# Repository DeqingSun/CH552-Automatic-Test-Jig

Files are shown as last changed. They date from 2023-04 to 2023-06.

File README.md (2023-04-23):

# CH552-Automatic-Test-Jig
This is a test jig that do automatic hardware test for CH55xduino

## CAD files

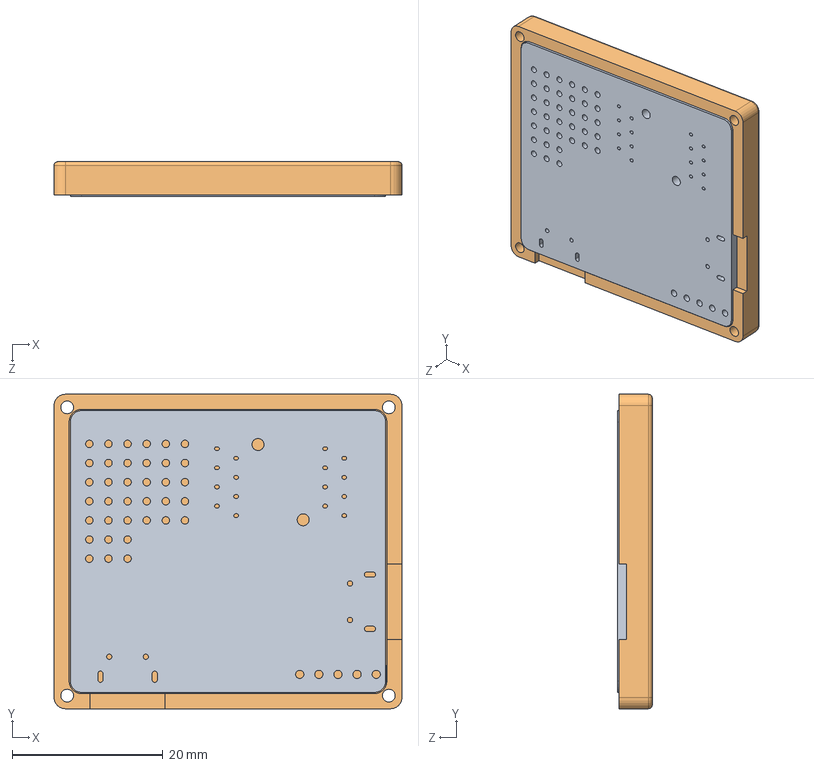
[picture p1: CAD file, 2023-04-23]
PCB/ch552_test_pcb_assembly.SLDASM
46.2 x 41.8 x 4.60 mm
ch552_test_pcb
ch552_test_pcb_case

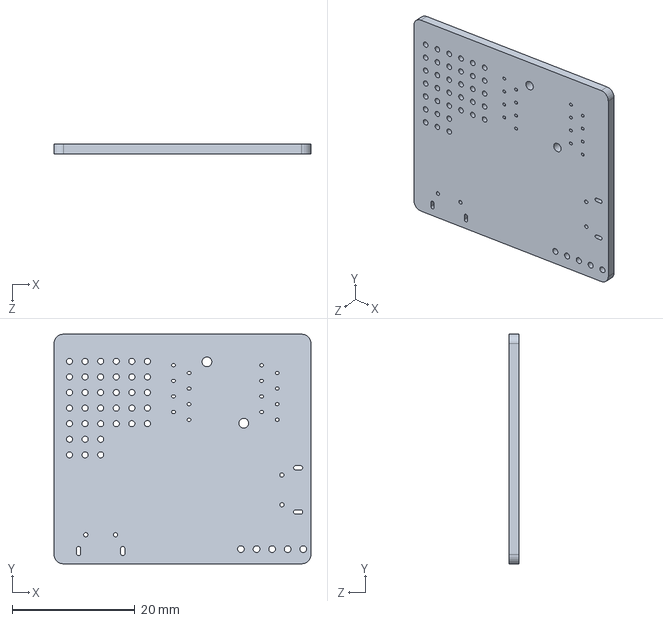
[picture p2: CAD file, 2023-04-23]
PCB/ch552_test_pcb.SLDPRT
41.9 x 37.4 x 1.60 mm

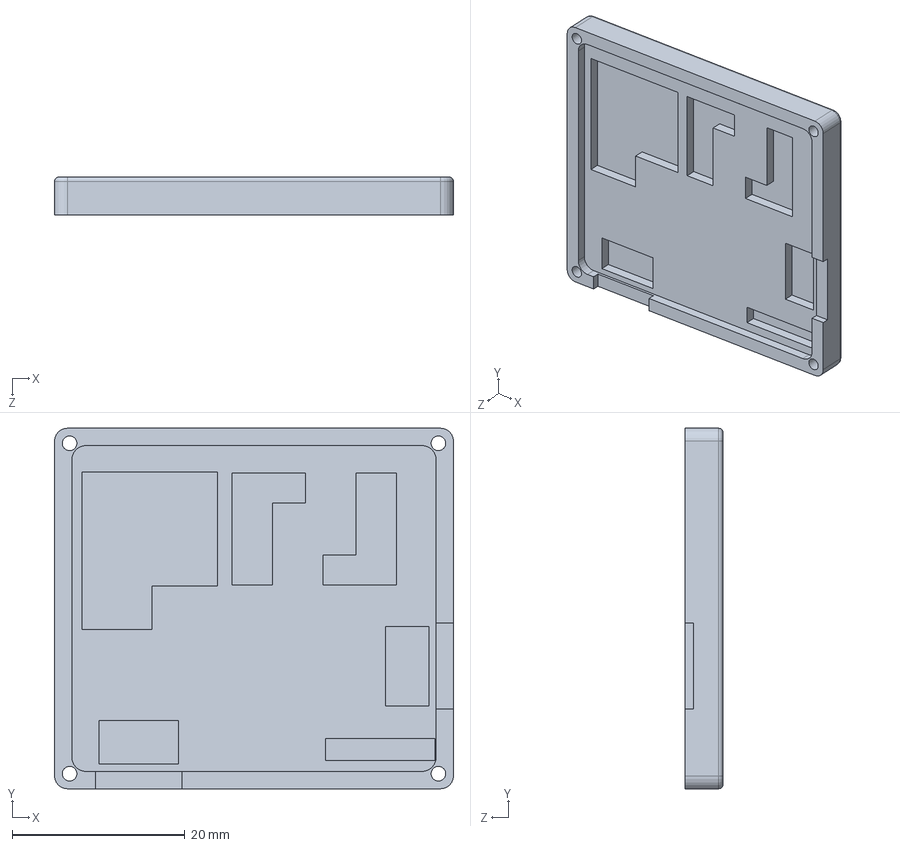
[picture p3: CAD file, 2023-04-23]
PCB/ch552_test_pcb_case.SLDPRT
46.2 x 41.8 x 4.40 mm

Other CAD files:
PCB/ch552_test_pcb_case.STL

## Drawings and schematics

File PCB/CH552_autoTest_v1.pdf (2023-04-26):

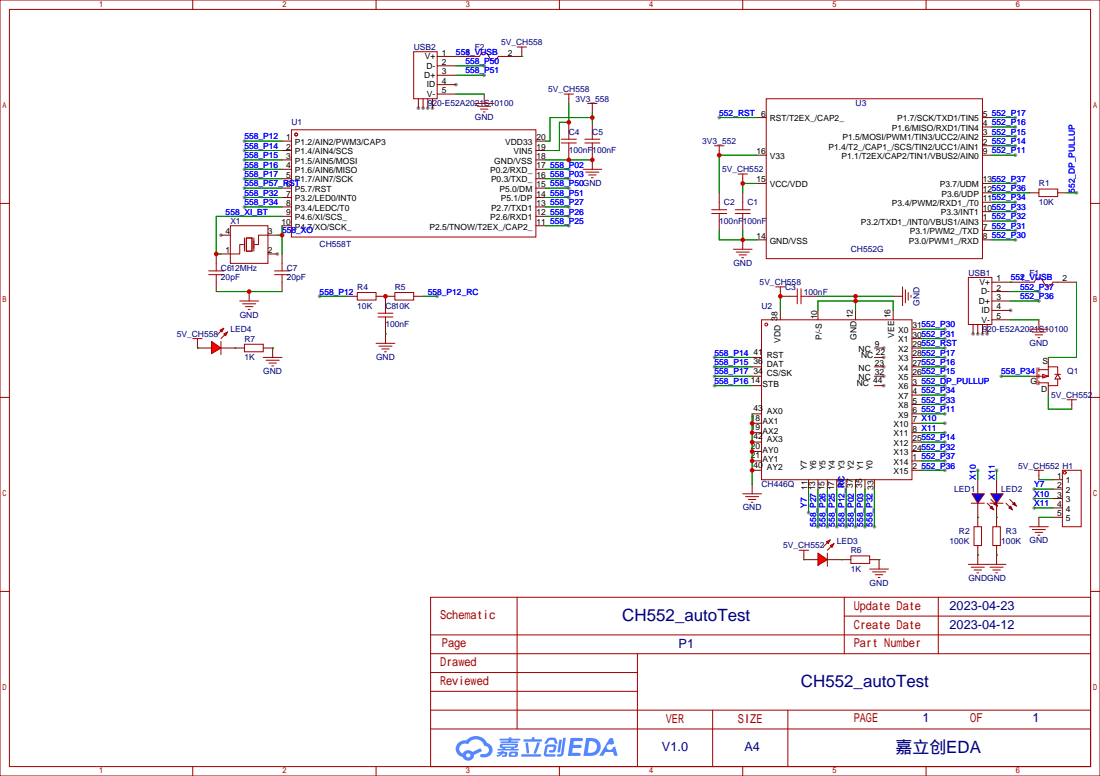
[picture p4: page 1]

1

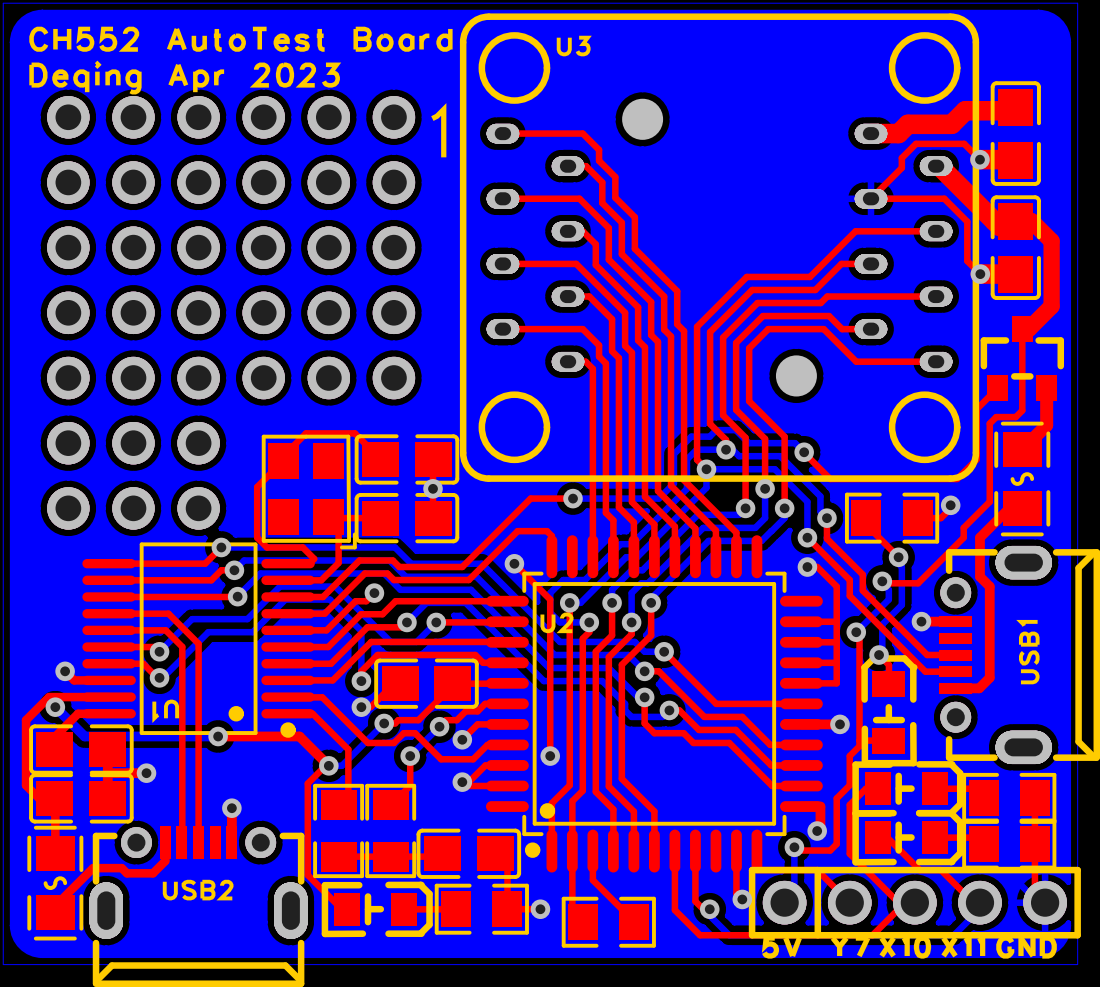
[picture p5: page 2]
5VY7X10X11GND; USB1; USB2

CH552 AutoTest Board Deqing Apr 2023

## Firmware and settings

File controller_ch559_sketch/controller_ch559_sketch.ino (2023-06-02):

//compiled with CH559, CH55xduino 0.0.17
//userUsbCdc used for customized description

#ifndef USER_USB_RAM
#error "This example needs to be compiled with a USER USB setting"
#endif

#include "src/userUsbCdc/USBCDC.h"
#include "ch446q_driver.h"
#include "pinUtil.h"
#include "util.h"

char rxSerialBuffer[16];
uint8_t rxSerialBufferPtr = 0;
uint8_t digitalPinSubscribed = 255;
uint8_t analogPinSubscribed = 255;
uint32_t digitalPinSubscribedLastPrintTime = 0;
uint32_t analogPinSubscribedLastPrintTime = 0;

char uart0RxBuffer[64];
uint8_t uart0RxBufferPtr = 0;
uint32_t uart0RxLastReceiveTime = 0;
char uart1RxBuffer[64];
uint8_t uart1RxBufferPtr = 0;
uint32_t uart1RxLastReceiveTime = 0;
volatile __bit rebootTargetInsteadOfSelfOn1200 = false;
volatile __bit needRebootTargetFlag = false;

void setup() {
  CH552_power(true);

  USBInit();
  CH446Q_init();
  CH446Q_reset();

}

void loop() {

  while (USBSerial_available()) {
    char serialChar = USBSerial_read();
    if ((serialChar == '\n') || (serialChar == '\r') ) {
      rxSerialBuffer[rxSerialBufferPtr] = '\0';
      if (rxSerialBufferPtr > 0) {
        //USBSerial_println(rxSerialBuffer);
        switch (rxSerialBuffer[0])
        {
          case 'I':
            if (rxSerialBufferPtr == 1) {
              CH446Q_reset();
              restoreAllPins();
              digitalPinSubscribed = 255;
              analogPinSubscribed = 255;
              USBSerial_println("I:Init System");
            }
            break;
          case 'C':
          case 'c':
            //connect channels on CH446Q
            if (rxSerialBufferPtr == 3) {
              uint8_t xChannel = hexToUchar(rxSerialBuffer[1]);
              uint8_t yChannel = hexToUchar(rxSerialBuffer[2]);
              uint8_t onOFF = (rxSerialBuffer[0] == 'C') ? 1 : 0;

              if ( (xChannel < 16) && (yChannel < 8)) {
                CH446Q_switch_channel(xChannel, yChannel, onOFF);
                USBSerial_print(rxSerialBuffer[0]);
                USBSerial_print(":Turn ");
                if (onOFF == 1) {
                  USBSerial_print("ON");
                } else {
                  USBSerial_print("OFF");
                }
                USBSerial_print(" X:");
                USBSerial_print(xChannel);
                USBSerial_print(", Y:");
                USBSerial_println(yChannel);
              }
            }
            break;
          case 'B':
            if (rxSerialBufferPtr == 1) {
              CH552_enter_bootloader();
              USBSerial_println("B: CH552 boot mode");
            }else if (rxSerialBufferPtr == 2) {
              if (rxSerialBuffer[1] == 'E'){
                rebootTargetInsteadOfSelfOn1200 = true;
                USBSerial_println("BE: CH552 reboot target on 1200");
              }else if (rxSerialBuffer[1] == 'e'){
                rebootTargetInsteadOfSelfOn1200 = false;
                USBSerial_println("Be: CH552 reboot self on 1200");
              }
            }
            break;
          case 'b':
            if (rxSerialBufferPtr == 1) {
              CH552_reboot_usercode();
              USBSerial_println("b: CH552 reboot usercode");
            }
            break;
          case 'R':
          case 'r':
            if (rxSerialBufferPtr == 3) {
              uint8_t pin = hexToUchar(rxSerialBuffer[1]) * 10 + hexToUchar(rxSerialBuffer[2]);
              uint8_t pinStatus = readPin(pin);
              USBSerial_print(rxSerialBuffer[0]);
              USBSerial_print(rxSerialBuffer[1]);
              USBSerial_print(rxSerialBuffer[2]);
              USBSerial_print((char)':');
              if (pinStatus == PIN_ERROR) {
                USBSerial_println("not valid");
              } else {
                USBSerial_println((char)('0' + pinStatus));
                if (rxSerialBuffer[0] == 'R') {
                  digitalPinSubscribed = 255;
                } else {
                  digitalPinSubscribed = pin;
                  digitalPinSubscribedLastPrintTime = millis();
                }
              }
            }
            break;
          case 'A':
          case 'a':
            if (rxSerialBufferPtr == 3) {
              uint8_t pin = hexToUchar(rxSerialBuffer[1]) * 10 + hexToUchar(rxSerialBuffer[2]);
              USBSerial_print(rxSerialBuffer[0]);
              USBSerial_print(rxSerialBuffer[1]);
              USBSerial_print(rxSerialBuffer[2]);
              USBSerial_print((char)':');
              if (pin != 12) {
                USBSerial_println("not valid");
              } else {
                analogRead(pin);
                USBSerial_println(analogRead(pin));
                if (rxSerialBuffer[0] == 'A') {
                  analogPinSubscribed = 255;
                } else {
                  analogPinSubscribed = pin;
                  analogPinSubscribedLastPrintTime = millis();
                }
              }
            }
            break;
          case 'W':
            if (rxSerialBufferPtr == 4) {
              uint8_t pin = hexToUchar(rxSerialBuffer[1]) * 10 + hexToUchar(rxSerialBuffer[2]);
              uint8_t value = hexToUchar(rxSerialBuffer[3]);
              USBSerial_print(rxSerialBuffer[0]);
              USBSerial_print(rxSerialBuffer[1]);
              USBSerial_print(rxSerialBuffer[2]);
              USBSerial_print((char)':');

              uint8_t pinStatus = writePin(pin, value);
              if (pinStatus == PIN_ERROR) {
                USBSerial_println("not valid");
              } else {
                USBSerial_println((char)('0' + pinStatus));
              }
            }
            break;
          case 'w':
            if (rxSerialBufferPtr == 5) {
              uint8_t pin = hexToUchar(rxSerialBuffer[1]) * 10 + hexToUchar(rxSerialBuffer[2]);
              uint8_t value = hexToUchar2_xdata(&rxSerialBuffer[3]);
              USBSerial_print(rxSerialBuffer[0]);
              USBSerial_print(rxSerialBuffer[1]);
              USBSerial_print(rxSerialBuffer[2]);
              USBSerial_print((char)':');
              if ( (pin == 12) || (pin == 25) ) {
                if (pin == 25) {
                  fastPWM2(value); //4K for P25
                } else {
                  fastPWM3(value);  //20K for P12
                }
                USBSerial_println((int)value);
              } else {
                USBSerial_println("not valid");
              }
            }
            break;
          case 'T':
          case 't':
            //set uart baudrate
            if (rxSerialBufferPtr == 2) {
              uint8_t baudrateMuliplexer = hexToUchar(rxSerialBuffer[1]);
              USBSerial_print(rxSerialBuffer[0]);
              USBSerial_print((char)':');
              if (baudrateMuliplexer == 0) {
                USBSerial_println("disable UART");
                if (rxSerialBuffer[0] == 'T') {
                  disableUART0();
                } else {
                  disableUART1();
                }
              } else if (baudrateMuliplexer > (115200 / 9600)) {
                USBSerial_println("not valid rate");
              } else {
                __xdata uint32_t baudrate = 9600L * baudrateMuliplexer;
                if (rxSerialBuffer[0] == 'T') {
                  PIN_FUNC |= bUART0_PIN_X;
                  Serial0_begin(baudrate);  //RXD0/TXD0 uses P0.2/P0.3
                } else {
                  Serial1_begin(baudrate);  //RXD1/TXD1 uses P2.6/P2.7
                }
                USBSerial_println(baudrate);
              }
            }
            break;
          case 'U':
          case 'u':
            {
              for (int i = 1; i < rxSerialBufferPtr; i++) {
                __data char charToSend = rxSerialBuffer[i];
                if (charToSend == '\\') {
                  if (rxSerialBuffer[i + 1] == 'n') {
                    charToSend = '\n';
                    i++;
                  } else if (rxSerialBuffer[i + 1] == 'r') {
                    charToSend = '\r';
                    i++;
                  }
                }
                if (rxSerialBuffer[0] == 'U') {
                  Serial0_write(charToSend);
                } else {
                  Serial1_write(charToSend);
                }
              }
            }
            break;
          default:
            break;
        }
        rxSerialBufferPtr = 0;
        break;
      }
    } else {
      if (rxSerialBufferPtr < (16 - 1)) {
        rxSerialBuffer[rxSerialBufferPtr] = serialChar;
        rxSerialBufferPtr++;
      } else {
        rxSerialBuffer[rxSerialBufferPtr] = '\0';
      }
    }
  }

  {
    __bit needToPrint = 0;
    if (Serial0_available()) {
      while (Serial0_available()) {
        __data char serialChar = Serial0_read();
        if (uart0RxBufferPtr < (64 - 1)) {
          uart0RxBuffer[uart0RxBufferPtr] = serialChar;
          uart0RxBufferPtr++;
          if (uart0RxBufferPtr == (64 - 1)) {
            needToPrint = 1;
            break;
          }
        }
        uart0RxLastReceiveTime = millis();
        if (serialChar == '\n') {
          needToPrint = 1;
          break;
        }
      }
    } else {
      if (uart0RxBufferPtr > 0) {
        if (((signed int)(millis() - uart0RxLastReceiveTime)) > 50) {
          needToPrint = 1;
        }
      }
    }

    if (needToPrint) {
      USBSerial_write((char)'U');
      USBSerial_write((char)':');
      for (__data uint8_t i = 0; i < uart0RxBufferPtr; i++) {
        __data char charToPrint = uart0RxBuffer[i];
        if (charToPrint == '\n') {
          USBSerial_write((char)'\\');
          USBSerial_write((char)'n');
        } else if (charToPrint == '\r') {
          USBSerial_write((char)'\\');
          USBSerial_write((char)'r');
        } else {
          USBSerial_write(charToPrint);
        }
      }
      USBSerial_write((char)'\n');
      uart0RxBufferPtr = 0;
    }
  }

  {
    __bit needToPrint = 0;
    if (Serial1_available()) {
      while (Serial1_available()) {
        __data char serialChar = Serial1_read();
        if (uart1RxBufferPtr < (64 - 1)) {
          uart1RxBuffer[uart1RxBufferPtr] = serialChar;
          uart1RxBufferPtr++;
          if (uart1RxBufferPtr == (64 - 1)) {
            needToPrint = 1;
            break;
          }
        }
        uart1RxLastReceiveTime = millis();
        if (serialChar == '\n') {
          needToPrint = 1;
          break;
        }
      }
    } else {
      if (uart1RxBufferPtr > 0) {
        if (((signed int)(millis() - uart1RxLastReceiveTime)) > 50) {
          needToPrint = 1;
        }
      }
    }

    if (needToPrint) {
      USBSerial_write((char)'u');
      USBSerial_write((char)':');
      for (__data uint8_t i = 0; i < uart1RxBufferPtr; i++) {
        __data char charToPrint = uart1RxBuffer[i];
        if (charToPrint == '\n') {
          USBSerial_write((char)'\\');
          USBSerial_write((char)'n');
        } else if (charToPrint == '\r') {
          USBSerial_write((char)'\\');
          USBSerial_write((char)'r');
        } else {
          USBSerial_write(charToPrint);
        }
      }
      USBSerial_write((char)'\n');
      uart1RxBufferPtr = 0;
    }
  }

  USBSerial_flush();

  //repeat output of digital pin status if subscribed
  if (digitalPinSubscribed != 255) {
    if (((int)(millis() - digitalPinSubscribedLastPrintTime)) > 25) {
      uint8_t pinStatus = readPin(digitalPinSubscribed);
      USBSerial_print((char)'r');
      if (digitalPinSubscribed < 10) {
        USBSerial_print((char)'0');
      }
      USBSerial_print((int)digitalPinSubscribed);
      USBSerial_print((char)':');
      USBSerial_println((char)('0' + pinStatus));
      digitalPinSubscribedLastPrintTime = millis();
    }
  }
  //repeat output of analog pin status if subscribed
  if (analogPinSubscribed != 255) {
    if (((int)(millis() - analogPinSubscribedLastPrintTime)) > 25) {
      USBSerial_print((char)'a');
      if (analogPinSubscribed < 10) {
        USBSerial_print((char)'0');
      }
      USBSerial_print((int)analogPinSubscribed);
      USBSerial_print((char)':');
      analogRead(analogPinSubscribed);
      USBSerial_println(analogRead(analogPinSubscribed));
      analogPinSubscribedLastPrintTime = millis();
    }
  }

  //reboot target take too long time to run in USB interrupt
  if (needRebootTargetFlag) {
    CH552_enter_bootloader();
    needRebootTargetFlag = false;
  }

}

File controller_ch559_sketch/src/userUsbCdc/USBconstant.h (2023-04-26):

#ifndef __CONST_DATA_H__
#define __CONST_DATA_H__

#include <stdint.h>
#include "include/ch5xx.h"
#include "include/ch5xx_usb.h"

#define  EP0_ADDR 0
#define  EP1_ADDR 10
#define  EP2_ADDR 20

#define  SET_LINE_CODING                0X20            // Configures DTE rate, stop-bits, parity, and number-of-character
#define  GET_LINE_CODING                0X21            // This request allows the host to find out the currently configured line coding.
#define  SET_CONTROL_LINE_STATE         0X22            // This request generates RS-232/V.24 style control signals.


extern __code uint8_t DevDesc[];
extern __code uint8_t CfgDesc[];
extern __code uint8_t LangDes[];
extern __code uint16_t SerDes[];
extern __code uint16_t Prod_Des[];
extern __code uint16_t CDC_Des[];
extern __code uint16_t Manuf_Des[];



extern __code uint16_t DevDescLen;
extern __code uint16_t CfgDescLen;
extern __code uint16_t LangDesLen;
extern __code uint16_t SerDesLen;
extern __code uint16_t Prod_DesLen;
extern __code uint16_t CDC_DesLen;
extern __code uint16_t Manuf_DesLen;

#endif

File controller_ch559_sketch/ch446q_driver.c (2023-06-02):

#include "ch446q_driver.h"

__xdata uint8_t currentMatrixStatus[16] = {0};  //16 X channels and 8 Y channels. 
__xdata uint8_t savedtMatrixStatus[16] = {0};  

void CH446Q_init() {
  digitalWrite(CH446_RST_PIN, LOW);
  pinMode(CH446_RST_PIN, OUTPUT);

  digitalWrite(CH446_DAT_PIN, LOW);
  pinMode(CH446_DAT_PIN, OUTPUT);

  digitalWrite(CH446_CLK_PIN, LOW);
  pinMode(CH446_CLK_PIN, OUTPUT);

  digitalWrite(CH446_STB_PIN, LOW);
  pinMode(CH446_STB_PIN, OUTPUT);
}

void CH446Q_reset() {
  digitalWrite(CH446_RST_PIN, HIGH);
  delayMicroseconds(10);
  digitalWrite(CH446_RST_PIN, LOW);

  for (__data uint8_t i = 0; i < 16; i++) {
    currentMatrixStatus[i] = 0;
  }
}

void CH446Q_switch_channel(__data uint8_t x, __xdata uint8_t y, __xdata uint8_t status) {
  //output y
  for (__data int8_t i = 2; i >= 0; i--) {
    digitalWrite(CH446_CLK_PIN, LOW);
    digitalWrite(CH446_DAT_PIN, (y >> i) & 0x01);
    delayMicroseconds(1);
    digitalWrite(CH446_CLK_PIN, HIGH);
    delayMicroseconds(1);
  }

  //output x
  for (__data int8_t i = 3; i >= 0; i--) {
    digitalWrite(CH446_CLK_PIN, LOW);
    digitalWrite(CH446_DAT_PIN, (x >> i) & 0x01);
    delayMicroseconds(1);
    digitalWrite(CH446_CLK_PIN, HIGH);
    delayMicroseconds(1);
  }

  //output ON
  digitalWrite(CH446_DAT_PIN, HIGH);
  delayMicroseconds(1);
  if (status) {
    digitalWrite(CH446_STB_PIN, HIGH);
    delayMicroseconds(1);
    digitalWrite(CH446_STB_PIN, LOW);
    currentMatrixStatus[x] |= 1<<y;
  }
  delayMicroseconds(1);

  //output OFF
  digitalWrite(CH446_DAT_PIN, LOW);
  delayMicroseconds(1);
  if (!status) {
    digitalWrite(CH446_STB_PIN, HIGH);
    delayMicroseconds(1);
    digitalWrite(CH446_STB_PIN, LOW);
    currentMatrixStatus[x] &= ~(1<<y);
  }
  delayMicroseconds(1);

  digitalWrite(CH446_CLK_PIN, LOW);
  digitalWrite(CH446_DAT_PIN, HIGH);
}

void CH446Q_save_matrix(){
  for (__data uint8_t i=0;i<16;i++){
    savedtMatrixStatus[i] = currentMatrixStatus[i];
    //USBSerial_println(currentMatrixStatus[i],HEX);
  }
}

void CH446Q_restore_matrix(){
  for (__data uint8_t i=0;i<16;i++){
    if ( savedtMatrixStatus[i] == currentMatrixStatus[i] ){
      continue;
    }
    for (__data uint8_t j=0;j<8;j++){
      if ((savedtMatrixStatus[i] & (1<<j)) != (currentMatrixStatus[i] & (1<<j))){
        if (savedtMatrixStatus[i] & (1<<j)){
          CH446Q_switch_channel(i,j,true);
        }else{
          CH446Q_switch_channel(i,j,false);
        }
      }
    }
  }
}

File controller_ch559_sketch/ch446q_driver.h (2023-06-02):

#ifndef __CH446Q_DRIVER_H
#define __CH446Q_DRIVER_H

#include <Arduino.h>

#define CH446_RST_PIN 14
#define CH446_DAT_PIN 15
#define CH446_CLK_PIN 17
#define CH446_STB_PIN 16

#define CH446_X_CH552_P30       0
#define CH446_X_CH552_P31       1
#define CH446_X_CH552_RST       2
#define CH446_X_CH552_P17       3
#define CH446_X_CH552_P16       4
#define CH446_X_CH552_P15       5
#define CH446_X_CH552_DP_PULLUP 6
#define CH446_X_CH552_P34       7
#define CH446_X_CH552_P33       8
#define CH446_X_CH552_P11       9
#define CH446_X_EXT_LED_10     10
#define CH446_X_EXT_LED_11     11
#define CH446_X_CH552_P14      12
#define CH446_X_CH552_P32      13
#define CH446_X_CH552_P37      14
#define CH446_X_CH552_P36      15

#define CH446_Y_CH559_P32      0
#define CH446_Y_CH559_P03      1
#define CH446_Y_CH559_P02      2
#define CH446_Y_CH559_P12_RC   3
#define CH446_Y_CH559_P25      4
#define CH446_Y_CH559_P26      5
#define CH446_Y_CH559_P27      6
#define CH446_Y_EXT_PIN_Y7     7

void CH446Q_init();
void CH446Q_reset();
void CH446Q_switch_channel(__data uint8_t x, __xdata uint8_t y, __xdata uint8_t status);
void CH446Q_save_matrix();
void CH446Q_restore_matrix();

#endif

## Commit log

2023-04-23 add some model
    [ch552_test_pcb.SLDPRT, ch552_test_pcb_assembly.SLDASM, ch552_test_pcb_case.SLDPRT]
2023-04-26 add CH446 driver
2023-04-28 add fast PWM
2023-04-28 add uart0 disable
2023-05-01 add board option
2023-05-01 jig test fade start, read has pull up issue
    [ch559_jig_code.py, controller_ch559_sketch.ino, jig_test_Fade.py]
2023-05-02 add voltage read
2023-05-03 update code order and make reboot only
    [controller_ch559_sketch.ino, pinUtil.c]
2023-05-04 update faster PWM for logic test
2023-05-12 print fewer lines for uart0 input
2023-05-12 print fewer lines for uart1 input
2023-05-12 add uart config
2023-06-01 fix pin output
2023-06-02 print info on webpage
2023-06-02 CH559 able to reboot target in Arduino upload
    [controller_ch559_sketch.ino]
